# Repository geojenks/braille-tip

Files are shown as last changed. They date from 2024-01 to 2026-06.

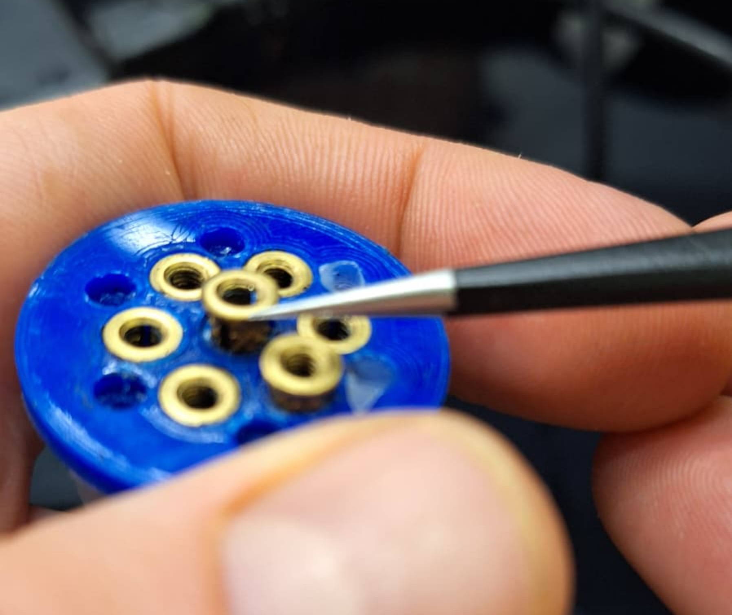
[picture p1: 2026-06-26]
docs/instructables/tubing_insert_coupler.png

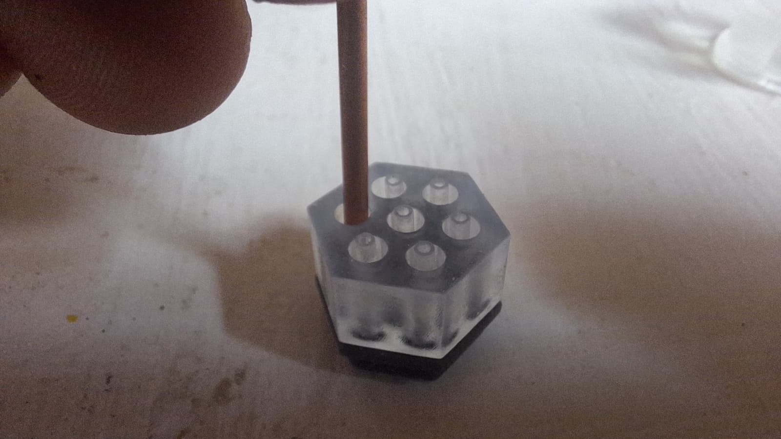
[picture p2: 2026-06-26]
docs/instructables/merged_assembly.jpeg

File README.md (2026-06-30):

# Braille-tip
data and code to accompany paper "Braille-tip: Structured Small-Footprint Tactile Sensor for High Acuity Dynamic Tactile Tasks"

## Build walkthrough
An interactive build & hand-off guide (BraillePen, with the Coil-Tac liquid-metal mechanism) is
published via GitHub Pages: **https://geojenks.github.io/braille-tip/** — source in [`docs/`](docs/).

# Code
In this folder are the main code for interpretting the sensor's signal. Included are 2 demos of readin data for the letter 'n' and the word `text' as presented in the paper. The main code "interpret_braille.m" includes instructions on how to load the data anr run the demos

# Fabrication
This folder contains the STL files for the mould needed to make the sensor, and the base of the sensor itself.

## Parametric CAD generator
[`cad/`](cad/) holds **braillegen** — an OpenSCAD generator that builds the tip, channel base,
pin tool and mould from a few parameters (taxel count, flat/curved membrane, barb vs heat-set
tube coupling, tube ID/OD). It prints a size + thinnest-feature + FDM-vs-resin report. See
[`cad/README.md`](cad/README.md).

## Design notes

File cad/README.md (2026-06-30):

# braillegen — parametric Braille-tip CAD generator

A single OpenSCAD source (`braillegen.scad`) that generates every printable part of a
Braille-tip / BraillePen sensor from a handful of design variables, so you can re-size the
array or swap the tube coupling without re-CADing anything by hand. It mirrors the build
forks in the [hand-off guide](https://geojenks.github.io/braille-tip/).

## What it makes

| `part=` | Part | Print in | Role |
|---|---|---|---|
| `tip` | soft sensor body | **silicone** (direct print) | taxel cavities + flat/curved membrane + channels + plug spigot |
| `base` | rigid channel base | FDM or resin | fans the channels out to the tube couplings (barb / heat-set) |
| `pin_tool` | pin/extruder tool | FDM or resin | forms the taxel cavities for the **cast** route |
| `mould_floor` | mould tray floor | FDM or resin | cast route |
| `mould_wall` | dam ring | FDM or resin | contains the silicone pour |
| `all` | every part, laid out | — | preview / sanity check (default) |

The taxels sit on a tight 2.5 mm grid but tubes and inserts are far bigger, so the **base is a
frustum**: channels fan *down-and-out* from the taxel grid to a coarser coupling grid on the
underside. The minimum coupling pitch and the base height are derived automatically from the
fitting you choose, so channels never collide and never leave the body.

## Interactive preview (`preview.html`)

A self-contained 3D viewer to mix &amp; match the three headline variables — **size** (taxel
rings), **spacing** (pitch) and **tube coupling** (barbs vs heat-push) — and orbit/zoom/slice
the result, with a live size + resin-verdict readout. It loads pre-rendered STLs, so first
generate them, then serve this folder (browsers block local `file://` STL fetches):

```bash
./make_previews.sh                 # or: .\make_previews.ps1   (writes preview_stl/)
python -m http.server              # then open http://localhost:8000/preview.html
```

Deep-link a specific configuration (handy from the build flowchart):
`preview.html?rings=3&pitch=2.5&coupling=heatset&view=base&cut=1`. Toggle **Cross-section** to
slice the part and see the internal channels.

## Requirements

[OpenSCAD](https://openscad.org) (tested on 2021.01). Either install it, or drop the portable
ZIP anywhere and point the exporter at `openscad.com`.

## Quick start

**GUI** — open `braillegen.scad` in OpenSCAD, `Window ▸ Customizer`, tweak the sliders, `F5` to
preview (set `cut = true` to see the internal channels), `F6` to render, then `File ▸ Export ▸ STL`.

**Headless, all parts + report** — from this folder:

```powershell
# Windows PowerShell
.\export_all.ps1 -Rings 2 -Coupling barb -Membrane curved
.\export_all.ps1 -Rings 1 -Coupling heatset -Membrane flat -OpenSCAD "C:\path\to\openscad.com"
```

```bash
# bash / git-bash / Linux / macOS
./export_all.sh
RINGS=1 COUPLING=heatset MEMBRANE=flat ./export_all.sh
FN=48 ./export_all.sh -D tube_id=1.2 -D tube_od=2.4   # any extra -D passes through
```

Both write the five STLs and a `report.txt` (overall size, thinnest wall/hole, FDM-vs-resin
verdict) into `out/`. To export one part by hand:

```bash
openscad -o base.stl -D 'part="base"' -D 'coupling="heatset"' braillegen.scad
```

## Parameters (the forks)

Grouped exactly as the OpenSCAD Customizer shows them. Everything is overridable on the CLI with `-D`.

**Taxel array** — `n_rings` (1→7, 2→19, 3→37 taxels), `pitch` (2.5 mm), `taxel_dia`,
`taxel_depth`, `rim`, `outline` (`hex`/`round`).

**Membrane** — `membrane` (`flat`/`curved`), `mem_thick`, `dome_rise` (curved apex).

**Tube coupling** — `coupling` (`barb`/`heatset`), `tube_id`, `tube_od`, `channel_dia`;
barb-only: `barb_len`, `barb_ridges`; heat-set-only: `heatset_dia` (printed insert pilot Ø),
`heatset_len`.

**Base** — `base_h` (auto-raised if the fan-out needs more), `plug_h`.

**Mould** — `mould_wall_t`, `mould_clear`, `mould_floor_h`, `mould_wall_h` (0 = auto).

**Output** — `part`, `cut` (slice for previewing channels), `$fn`.

## Printing notes

- The console/`report.txt` **resin verdict** keys off the smallest feature. With 1 mm taxels,
  ~0.8 mm membrane and ~0.8 mm channels you are below ~1 mm everywhere — **print the `tip` and
  `base` in resin/SLA** (Form 3 etc.). FDM is fine for the mould and pin tool.
- Resin that contacts platinum-cure silicone must be **fully UV-cured + IPA-washed** first, or it
  inhibits the cure. (See the guide.)
- **Barb caveat:** a barb has to fit *inside* the tube, so its bore can't approach the tube ID. If
  `channel_dia` ≳ `tube_id − 0.5` the report shows a near-zero barb wall — drop `channel_dia`, or
  use the `heatset` coupling instead (it isn't size-limited that way). Default `tube_id=1.0` +
  `channel_dia=0.8` deliberately trips this so the warning is visible.
- `$fn` drives both quality and render time: the `base` CSG is the slow part (~5 s at `$fn=28`,
  ~1 min at 48). Export at 36–48; preview lower.

## Roadmap

- Arbitrary face outline: lay taxels on the same lattice, then crop the hex packing to any 2-D
  shape (`outline` already abstracts hex vs round — a polygon mask slots in here).
- A web sub-page on the guide exposing `cavity Ø`, `pitch`, etc. as live controls.

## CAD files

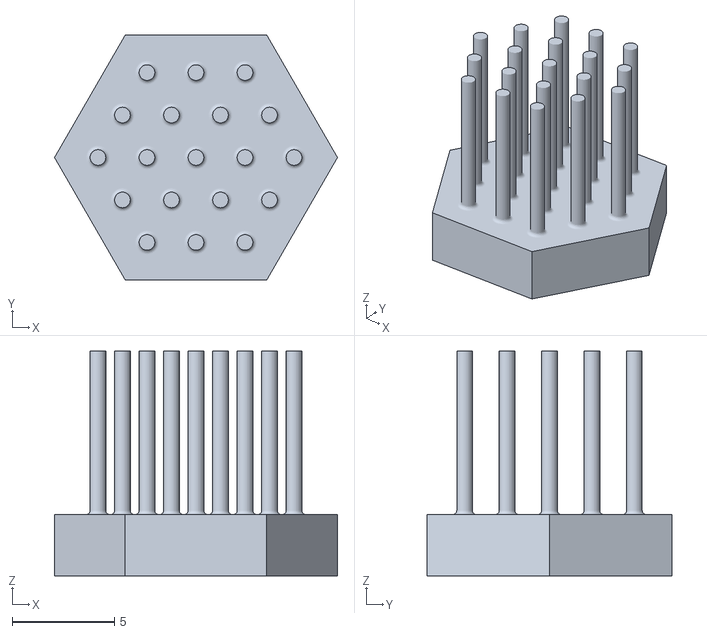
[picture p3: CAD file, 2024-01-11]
Fabrication/extruder_for_barbed_larger_spacing.STL
13.9 x 12.0 x 11.0

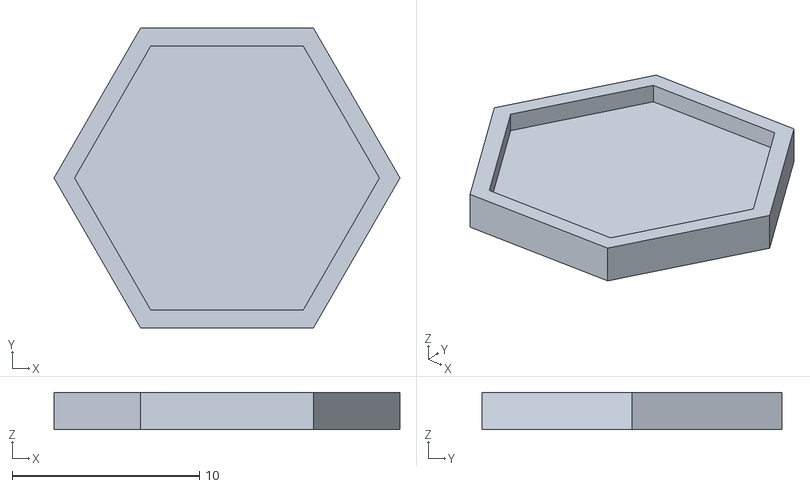
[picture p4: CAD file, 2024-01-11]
Fabrication/silicone_base.STL
18.5 x 16.0 x 2.00

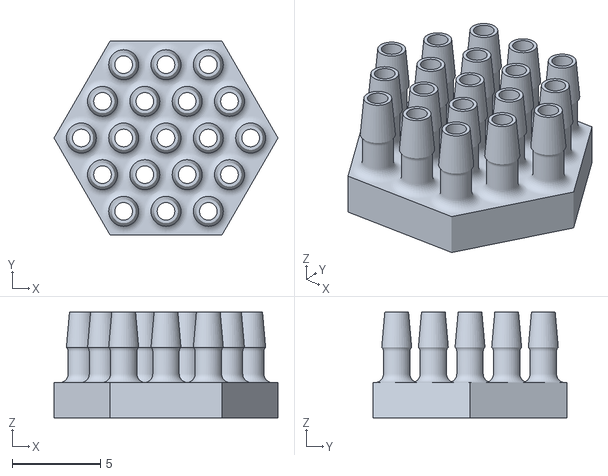
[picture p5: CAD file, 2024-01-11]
Fabrication/base_with_barbs_larger_spacing_thicker.STL
12.7 x 11.0 x 6.00

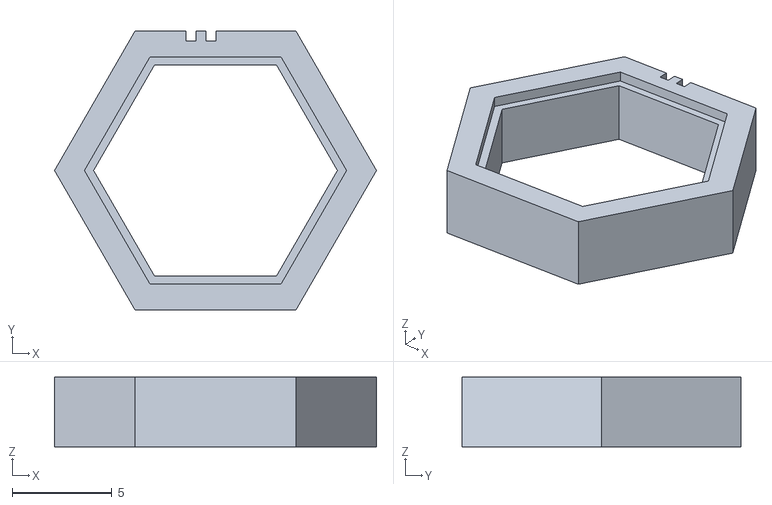
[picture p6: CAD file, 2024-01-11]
Fabrication/silicone_edging_1.STL
16.2 x 14.0 x 3.50

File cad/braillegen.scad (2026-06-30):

// braillegen.scad — parametric Braille-tip / BraillePen CAD generator
// =====================================================================
// A single parametric source that emits every printable part of a
// Braille-tip sensor, sized from a handful of design variables. It mirrors
// the build "forks" in the hand-off guide (https://geojenks.github.io/braille-tip/):
//
//   * Taxel array      — a centred-hexagonal lattice. n_rings drives the count:
//                        rings 1 -> 7, 2 -> 19, 3 -> 37 ... (3r^2+3r+1).
//   * Membrane         — flat or curved (fingertip-domed) sensing face.
//   * Tube coupling    — printed BARBS (tube slips over) or HEAT-SET inserts
//                        (push-fit coupler screws in). Both need tube ID/OD;
//                        heat-set also needs the insert pilot diameter.
//
// The taxels sit at 2.5 mm pitch but tubes/inserts are far bigger, so the
// rigid base is a FRUSTUM: channels fan down-and-out from the tight taxel grid
// to a coarser coupling grid on the underside. The minimum coupling pitch and
// the base height are derived automatically from the chosen fitting so the
// channels never collide and never leave the body.
//
// Parts emitted (choose with `part`):
//   tip          — soft sensor body for DIRECT SILICONE PRINTING (taxel cavities,
//                  flat/curved membrane, channels, plug spigot).
//   base         — rigid channel base with the chosen couplings (FDM or resin).
//   pin_tool     — pin/extruder tool that forms the taxel cavities (CAST route).
//   mould_floor  — tray floor for the cast route.
//   mould_wall   — dam ring that contains the silicone pour.
//   all          — every part laid out side by side (preview / sanity check).
//
// Headless export (one STL per part), e.g.:
//   openscad -o tip.stl  -D 'part="tip"'  braillegen.scad
//   openscad -o base.stl -D 'part="base"' -D 'coupling="heatset"' braillegen.scad
// A print-readiness report (overall size, thinnest wall/hole, FDM-vs-resin
// verdict) is echoed to the console on every render. See export_all.* / README.
// =====================================================================

/* [Taxel array] */
// taxel rings out from centre (1 -> 7 taxels, 2 -> 19, 3 -> 37 ...)
n_rings     = 2;     // [1:1:5]
// taxel centre-to-centre spacing (mm) — 2.5 matches Braille dot pitch
pitch       = 2.5;
// taxel cavity diameter (mm)
taxel_dia   = 1.0;
// taxel cavity depth into the silicone (mm)
taxel_depth = 1.2;
// silicone/base rim left beyond the outermost taxels (mm)
rim         = 1.2;
// sensing-face / base outline
outline     = "hex"; // [hex, round]

/* [Membrane] */
// flat (reads flat Braille) or curved (fingertip dome)
membrane    = "curved"; // [flat, curved]
// silicone thickness over each taxel (mm)
mem_thick   = 0.8;
// apex rise of the curved face above the rim (mm) — ignored when flat
dome_rise   = 0.8;

/* [Tube coupling] */
// printed barbs (tube slips over) or heat-set threaded inserts (push-fit coupler)
coupling    = "barb"; // [barb, heatset]
// tubing inner diameter (mm)
tube_id     = 1.0;
// tubing outer diameter (mm)
tube_od     = 2.0;
// barb length below the base (mm) — barb route only
barb_len    = 5.0;
// number of barb ridges — barb route only
barb_ridges = 2;     // [1:1:4]
// printed pilot-hole diameter the heat-set insert melts into (mm) — heat-set route only
heatset_dia = 4.0;
// heat-set insert depth (mm) — heat-set route only
heatset_len = 5.0;
// fluid channel diameter through the parts (mm)
channel_dia = 0.8;

/* [Base] */
// requested rigid base height (mm); auto-raised if the fan-out needs more
base_h      = 6.0;
// depth the tip's plug spigot sinks into the base (mm)
plug_h      = 2.0;

/* [Mould (cast route)] */
// dam wall thickness (mm)
mould_wall_t  = 2.0;
// clearance between silicone and dam (mm)
mould_clear   = 0.3;
// mould floor thickness (mm)
mould_floor_h = 2.0;
// dam height (mm); 0 = auto from silicone thickness
mould_wall_h  = 0;

/* [Output] */
part        = "all"; // [all, tip, base, pin_tool, mould_floor, mould_wall]
// preview only: slice the part on the XZ plane to reveal internal channels
cut         = false; // [false, true]
$fn         = 48;

// ---- advisory limits used by the report / resin verdict ----
WALL_MIN_OK = 1.0;   // walls/holes below this -> resin recommended
FEAT_RESIN  = 1.0;   // features below this -> resin strongly recommended
FIT_CLEAR   = 0.15;  // plug<->socket clearance (mm)

// =====================================================================
//  Geometry helpers
// =====================================================================
assert(n_rings >= 1, "n_rings must be >= 1 (at least 7 taxels)");

// centred-hexagonal lattice in axial coords, deterministic order
function axial_pts(R) = [ for (q=[-R:R]) for (r=[-R:R]) if (abs(q+r) <= R) [q,r] ];
function ax2xy(a, p)  = [ p*(a[0] + a[1]/2), p*(sqrt(3)/2)*a[1] ];
function lattice(R,p) = [ for (a=axial_pts(R)) ax2xy(a,p) ];
function max_r(pts)   = max([ for (p=pts) norm(p) ]);

taxels   = lattice(n_rings, pitch);
nt       = len(taxels);

// sensing-face / tip footprint radius (circumradius for hex outline)
face_r   = max_r(taxels) + taxel_dia/2 + rim;

// minimum coupling pitch so neighbouring fittings + walls fit
coupl_w     = (coupling == "barb") ? tube_od : heatset_dia;     // fitting footprint
min_cpitch  = coupl_w + 2*WALL_MIN_OK;
cpitch      = max(pitch, min_cpitch);
couplings   = lattice(n_rings, cpitch);                          // index-matched to taxels
coupl_r     = max_r(couplings) + coupl_w/2 + rim;               // base underside radius

// auto base height: keep fan-out angle <= ~45 deg and clear the socket floor
max_horiz   = max_r(taxels) * (cpitch/pitch - 1);
base_h_min  = plug_h + max_horiz + 1.0;
base_h_eff  = max(base_h, base_h_min);

// tip vertical bookkeeping (z=0 at tip bottom / plug base)
base_pad    = 0.8;                                  // silicone below the cavities
core_h      = base_pad + taxel_depth + mem_thick;   // silicone thickness (plug top -> flat face)
z_cav_floor = plug_h + base_pad;
z_face_flat = plug_h + core_h;
plug_r      = max(face_r - 1.2, face_r*0.6);

// dome sphere for the curved face: meets z_face_flat at r=face_r, rises dome_rise at centre
dome_R      = (face_r*face_r + dome_rise*dome_rise) / (2*dome_rise);

// =====================================================================
//  Primitive modules
// =====================================================================
// hex (circumradius r) or round slab, h tall, sitting on its own z=0
module slab(r, h) {
    if (outline == "hex") cylinder(h=h, r=r, $fn=6);
    else                  cylinder(h=h, r=r);
}

// align +z to vector v, then draw children
module orient(v) {
    L  = norm(v);
    vn = v / max(L, 1e-9);
    ax = cross([0,0,1], vn);
    la = norm(ax);
    if (la < 1e-9) { if (vn[2] < 0) rotate([180,0,0]) children(); else children(); }
    else rotate(acos(vn[2]), ax) children();
}

// solid cylinder from p1 to p2
module seg(p1, p2, d) {
    translate(p1) orient(p2 - p1) cylinder(h=norm(p2-p1), d=d, $fn=24);
}

// =====================================================================
//  TIP — soft body for direct silicone printing (or the cast result shape)
// =====================================================================
module tip_outer() {                       // body above the plug, starts at its own z=0
    if (membrane == "flat") {
        slab(face_r, core_h);
    } else {
        union() {
            slab(face_r, core_h);
            translate([0,0,core_h]) intersection() {
                translate([0,0,dome_rise - dome_R]) sphere(r=dome_R, $fn=max($fn,96));
                slab(face_r, dome_rise + 0.01);
            }
        }
    }
}

module part_tip() {
    difference() {
        union() {
            slab(plug_r, plug_h);                       // plug spigot
            translate([0,0,plug_h]) tip_outer();        // sensing body (+dome)
        }
        // sealed taxel cavities (mem_thick of silicone left above each)
        for (t = taxels)
            translate([t[0], t[1], z_cav_floor]) cylinder(h=taxel_depth, d=taxel_dia);
        // channels: cavity floor down through the plug bottom
        for (t = taxels)
            translate([t[0], t[1], -0.1]) cylinder(h=z_cav_floor + 0.2, d=channel_dia);
    }
}

// =====================================================================
//  BASE — rigid channel frustum with the chosen couplings
// =====================================================================
module base_body() {                       // frustum: tip footprint on top, coupling footprint on bottom
    hull() {
        translate([0,0,base_h_eff - 0.01]) slab(face_r,  0.01);
        slab(coupl_r, 0.01);
    }
}
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

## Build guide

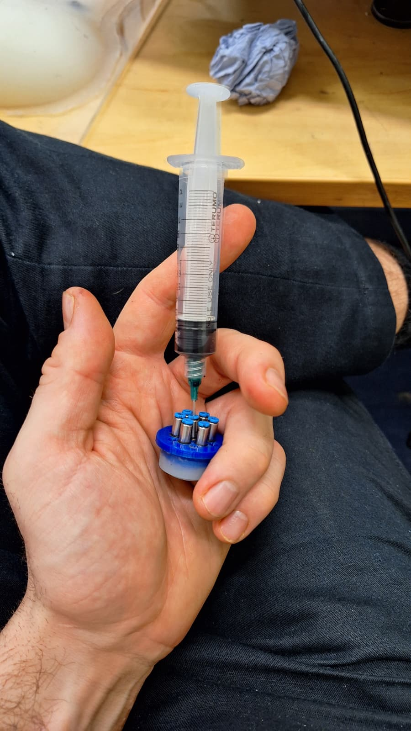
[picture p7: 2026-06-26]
docs/instructables/filling_sequence.png

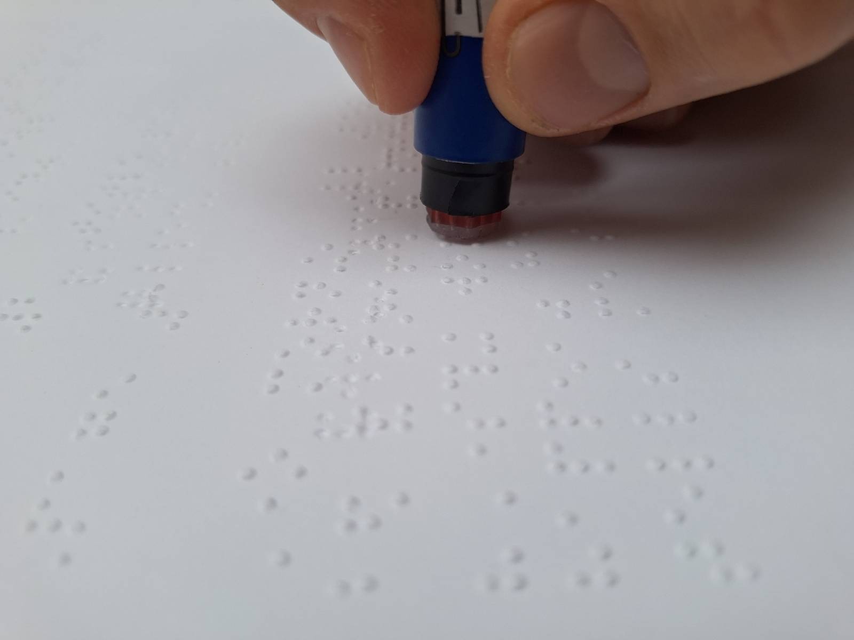
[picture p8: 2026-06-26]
docs/instructables/1.jpeg

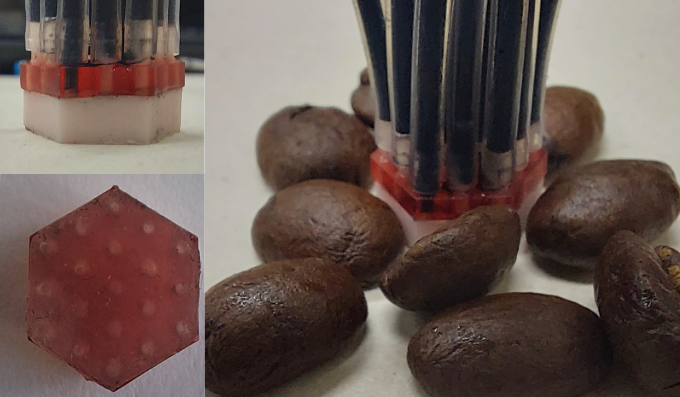
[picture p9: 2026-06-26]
docs/instructables/taxel_face_closeup.png

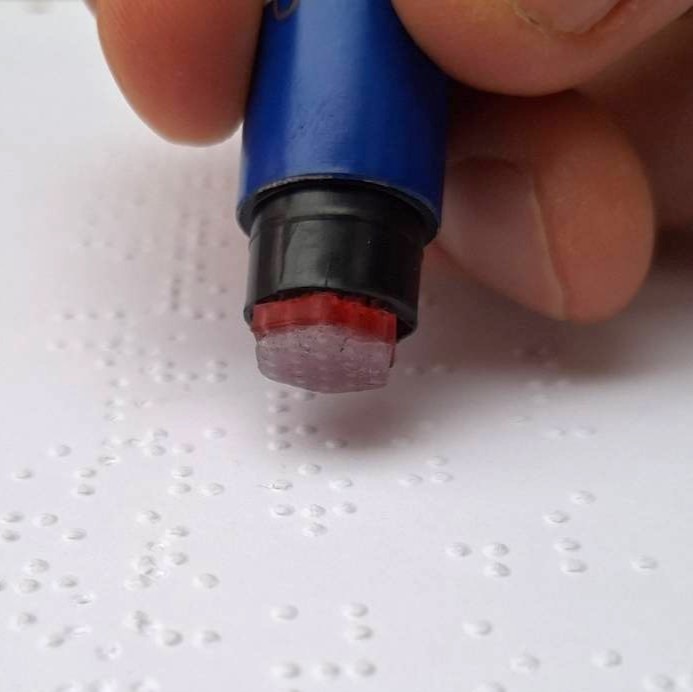
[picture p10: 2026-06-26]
docs/instructables/tip_and_braille.jpeg

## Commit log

2023-11-06 added CAD models
    [base_with_barbs_larger_spacing_thicker.SLDPRT, extruder_for_barbed_larger_spacing.SLDPRT, silicone.SLDPRT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]
2024-01-10 update
    upload of all up to date data, code, and 3D models
    [base_with_barbs_larger_spacing_thicker.SLDPRT, extruder_for_barbed_larger_spacing.SLDPRT, silicone.SLDPRT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]
2024-01-11 Fabrication model update
    [base_with_barbs_larger_spacing_thicker.SLDPRT, base_with_barbs_larger_spacing_thicker.STL, extruder_for_barbed_larger_spacing.SLDPRT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]
2026-06-26 Encode 2B→tubing dependency: direct-printed channels are the tubing
    When the tip is direct-printed (Fork 2B) the printed resin channels act as the
    tubing, so Fork 4 is skipped. Configurator greys out the tubing node and the
    filtered view hides Step 4; notes flag the unexplored "printed tubing" path for
    the optical readout.
2026-06-26 Reframe Fork 4 as channel strategy (independent of tip fabrication)
    Replace the incorrect "direct-print tip => skip tubing" dependency with the real
    choice: printed channel matrix (high design / low fabrication, no coupling) vs
    coupled tubing (low design / higher fabrication; barbs or threaded insert +
    coupler). This is independent of how the tip is made. Flags the unexplored
    printed-channels-for-optical ("printed tubing") combination.
2026-06-26 Add dark mode (auto + toggle) and a Code & CAD link
    Refactor all colours onto CSS variables and add a dark palette that follows
    prefers-color-scheme by default, with an in-page toggle (persisted to
    localStorage, no-flash init). Add a "Code & CAD" GitHub link in the header and
    hero.
2026-06-30 Add braillegen: parametric OpenSCAD Braille-tip generator
    Single .scad emits tip, channel base, pin tool and mould from a few
    parameters: taxel rings (7/19/37...), flat vs curved membrane, and barb
    vs heat-set tube coupling (tube ID/OD, insert pilot). Channels fan out
    from the 2.5mm taxel grid to a coarser coupling grid on a frustum base;
    min coupling pitch and base height auto-derive from the fitting. Prints
    a size + thinnest-feature + FDM-vs-resin report. Includes PowerShell and
    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
    [braillegen.scad]
2026-06-30 Add interactive 3D preview viewer for braillegen
    preview.html: self-contained Three.js viewer to mix & match size (taxel
    rings), spacing (pitch) and coupling (barb/heat-push), with orbit/zoom,
    a clipping-plane cross-section, a live size/resin-verdict report, and
    ?rings=&pitch=&coupling=&view=&cut= deep-links. Loads pre-rendered STLs
    made by make_previews.{ps1,sh}. preview_stl/ is gitignored (regenerable).
